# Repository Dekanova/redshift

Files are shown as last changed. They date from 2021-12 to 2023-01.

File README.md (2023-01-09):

# Redshift 

This is the central repository for work on the Redshift PCB.

## Features
- 8kHz polling (USB 2.0 HighSpeed)
- usb-C port
- PAW 3399

## Usage
- KiCad 6.0+ must be installed
- Openinput library from kicad content&lib manager in KiCad

**NOTE:** Encoder 3d file is intentionally not included. If you wish to add it, models are freely downloaded from Alps Alpine [website](https://tech.alpsalpine.com/e/products/cad.html) under EC10E.

## Board Notes
- If connecting USB and debug connectors at the same time, ensure debug supply voltage is under 5v. (some JTAG debuggers have this) 5v supply from debug pins are OK as long as USB is unplugged.
- PcbNew grid size used is 0.1mm

### Credits
A huge thanks to openinput for their generic [KiCad lib](https://github.com/openinput-fw/openinput-kicad-library), as well as their [fully developed PCBs](https://github.com/openinput-fw/sammy) which this PCB is largely based off of.

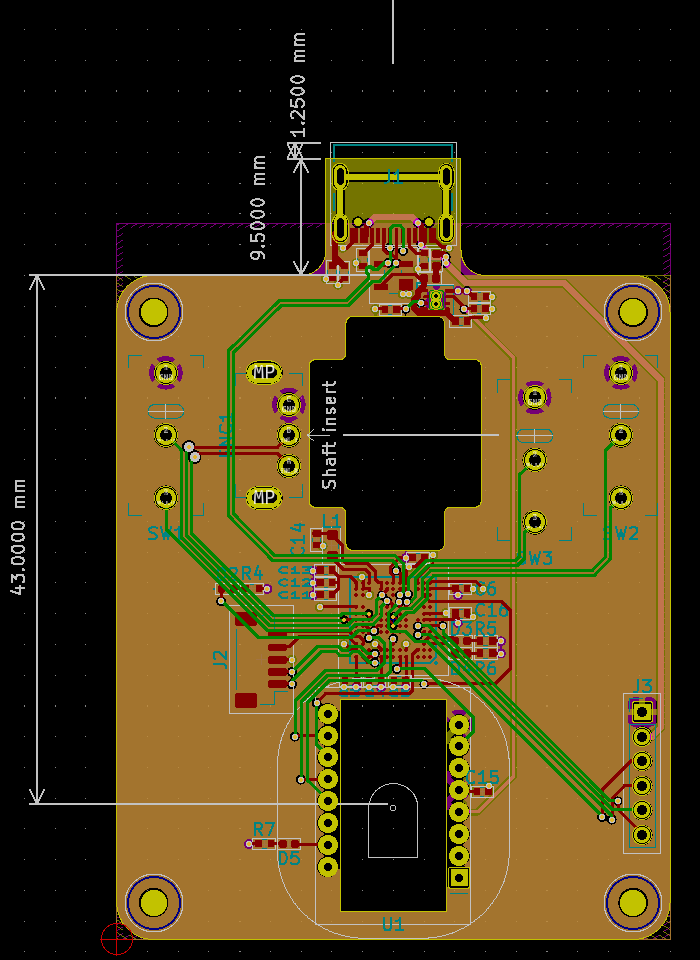
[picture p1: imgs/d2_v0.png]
2d view of PCB Title

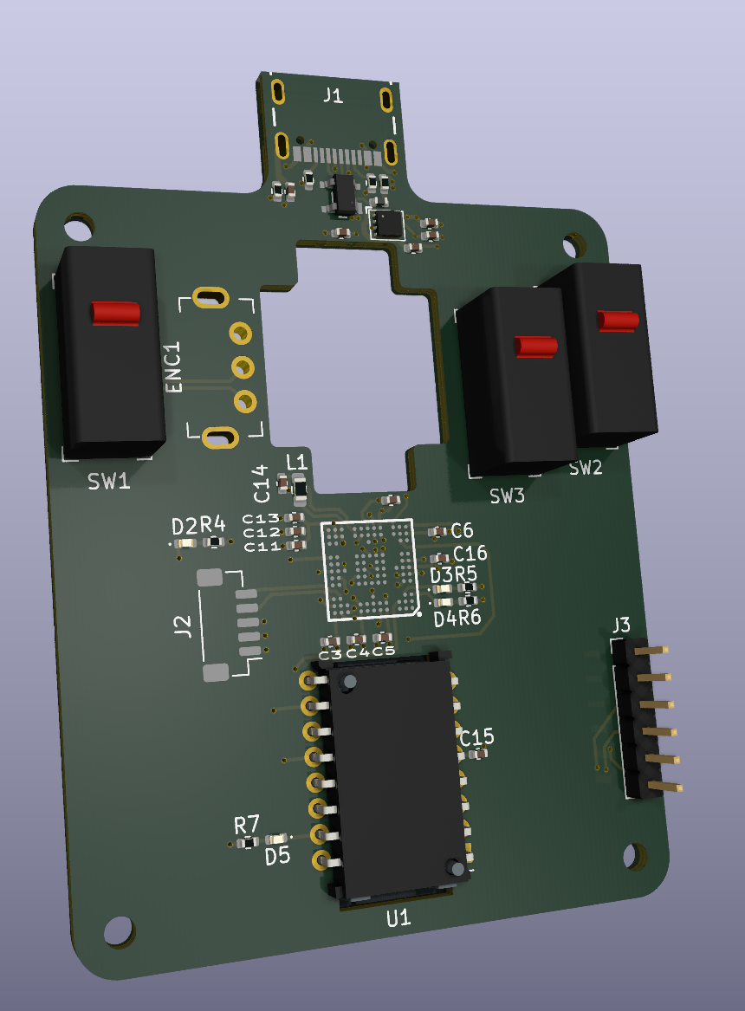
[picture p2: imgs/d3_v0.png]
3d view of PCB Title


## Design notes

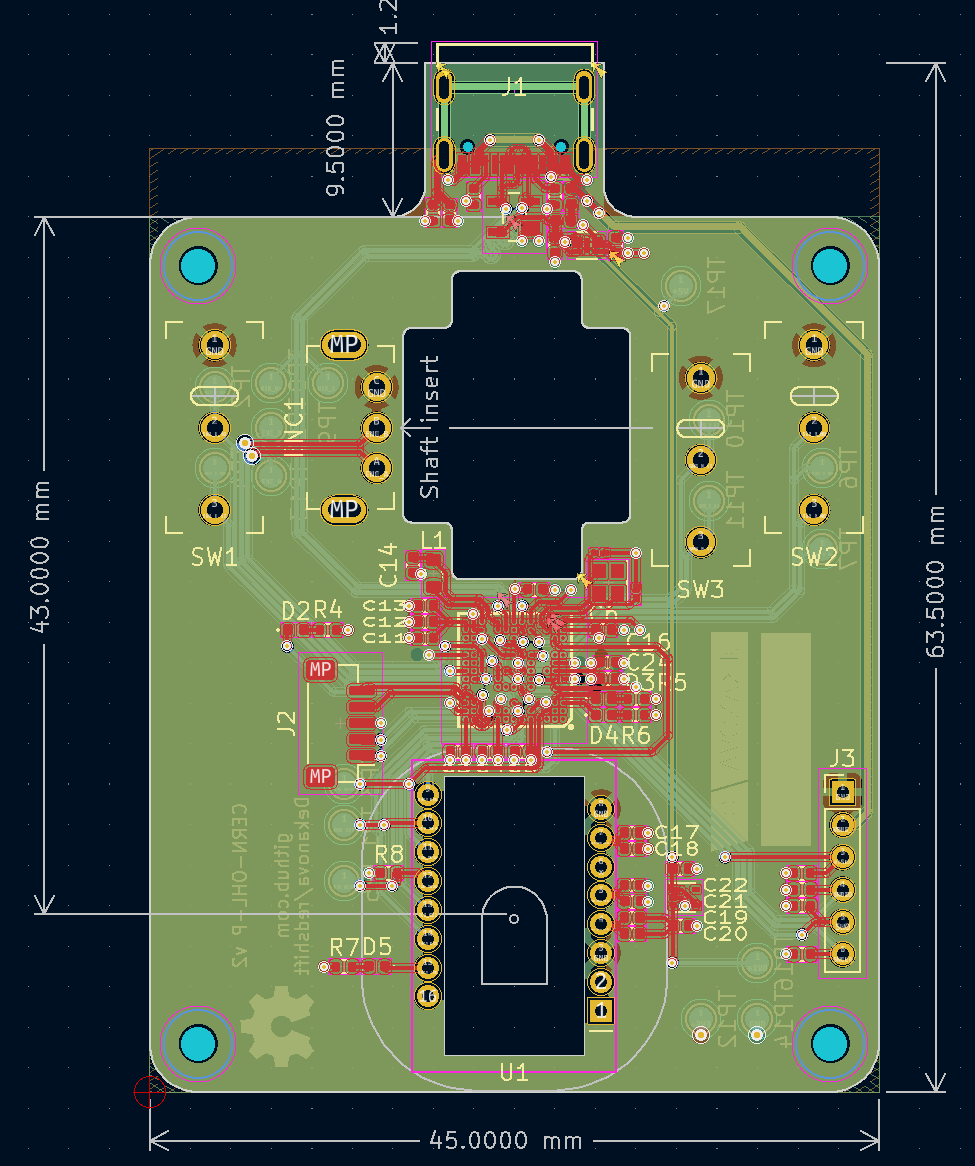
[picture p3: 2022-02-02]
imgs/2d_v0-1.png

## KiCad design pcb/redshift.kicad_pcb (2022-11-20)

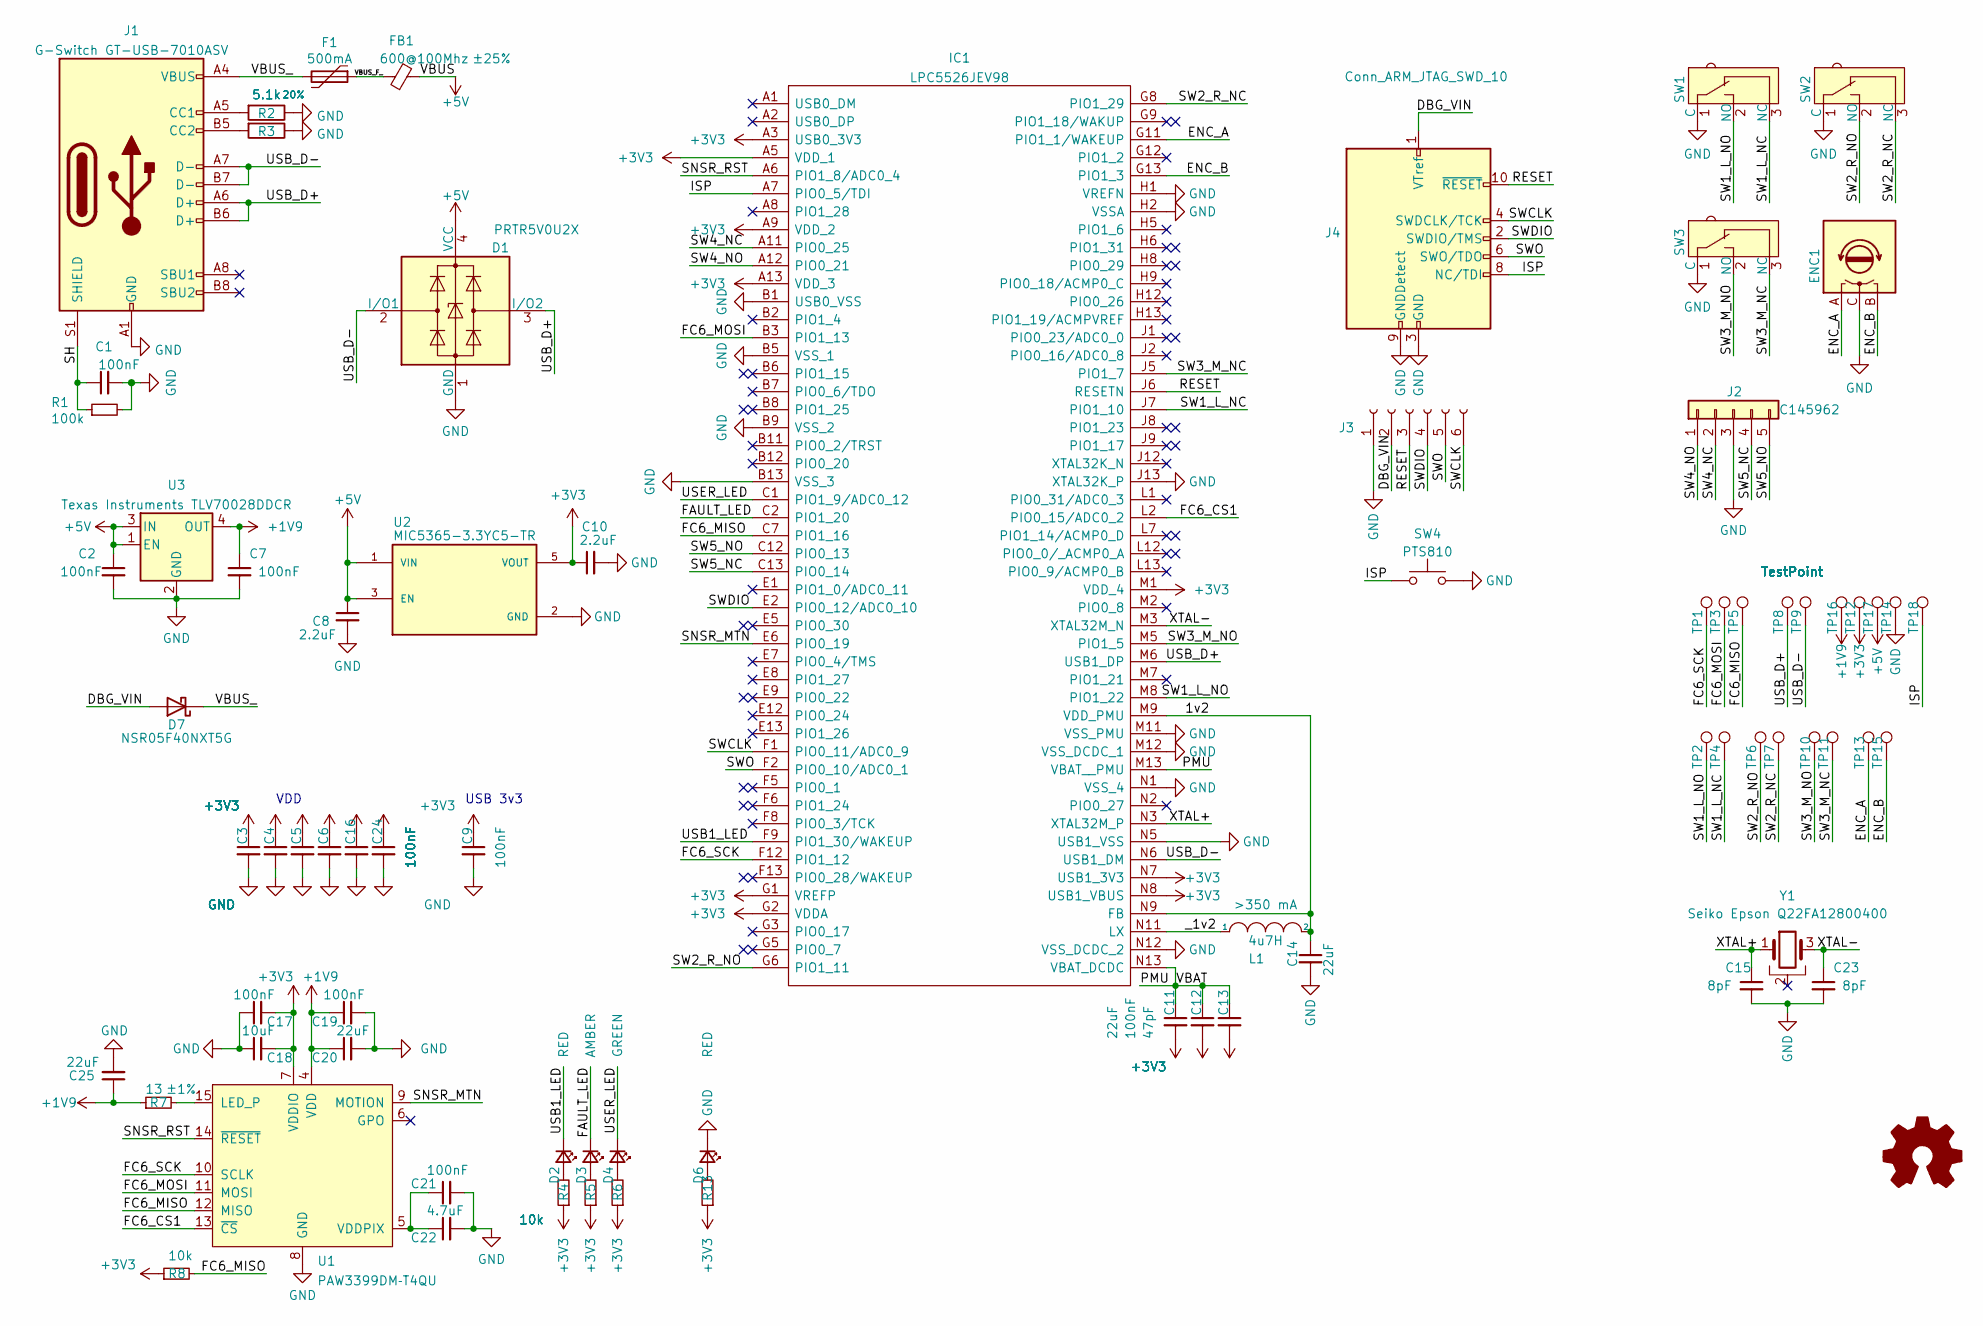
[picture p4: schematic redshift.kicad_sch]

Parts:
C1, C2, C3, C4, C5, C6, C7, C9, C12, C16, C17, C19, C21, C24: 100nF; C_0402_1005Metric; LCSC C1525
C8, C10: 2.2uF; C_0402_1005Metric; LCSC C12530
C11, C14, C20, C25: 22uF; C_0603_1608Metric; LCSC C59461
C13: 47pF; C_0402_1005Metric; LCSC C1567
C15, C23: 8pF; C_0402_1005Metric; LCSC C1578
C18: 10uF; C_0402_1005Metric; LCSC C15525
C22: 4.7uF; C_0402_1005Metric; LCSC C23733
D1: PRTR5V0U2X; BF994S; LCSC C12333
D2, D6: RED; LED_0402_1005Metric; LCSC C965790
D3: AMBER; LED_0402_1005Metric; LCSC C401111
D4: GREEN; LED_0402_1005Metric; LCSC C401111
D7: NSR05F40NXT5G; D_0402_1005Metric; LCSC C146713
ENC1: Rotary_Encoder; RotaryEncoder_Horizontal
F1: 500mA; Fuse_0402_1005Metric; LCSC C17168
FB1: 600@100Mhz; L_0402_1005Metric; Tolerance ±25%; LCSC C142082
IC1: LPC5526JEV98; BGA98C50P13X13_700X700X97N; Manufacturer_Part_Number LPC5528JEV98K; Mouser Part Number 771-LPC5528JEV98K
J1: G-Switch GT-USB-7010ASV; GCT_USB4105-GF-A; LCSC C2988369
J2: C145962; JST_SH_BM05B-SRSS-TB_1x05-1MP_P1.00mm_Vertical
J3: C2935905; PinHeader_1x06_P2.00mm_Vertical
J4: Conn_ARM_JTAG_SWD_10; PinHeader_2x05_P1.27mm_Vertical_SMD; LCSC C2935458
L1: 4u7H; L_0805_2012Metric; LCSC C63166
R1: 100k; R_0402_1005Metric; LCSC C25741
R2, R3: 5.1k; R_0402_1005Metric; Tolerance 20%; LCSC C25905
R4, R5, R6, R8, R13: 10k; R_0402_1005Metric; LCSC C25744
R7: 13; R_0402_1005Metric; Tolerance ±1%; LCSC C368403
SW1, SW2, SW3: SW_SP; SW_Micro_Switch
SW4: PTS810; SW_SPST_B3U-1000P; LCSC C231329
TP1, TP2, TP3, TP4, TP5, TP6, TP7, TP8, TP9, TP10, TP11, TP12, TP13, TP14, TP15, TP16, TP17, TP18: TestPoint; TestPoint_Pad_D1.5mm
U1: PAW3399DM‐T4QU; PXI-DIP-16
U2: MIC5365-3.3YC5-TR; SOT-23-5; PARTREV 3.1 - July 16, 2013; LCSC C82942
U3: Texas Instruments TLV70028DDCR; SOT-23-5; LCSC C507266
Y1: Seiko Epson Q22FA12800400; LCSC C255875

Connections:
+1V9: C7.1, C19.1, C20.1, C25.1, R7.1, TP16.1, U1.4 (VDD), U3.4 (OUT)
+3V3: C3.1, C4.1, C5.1, C6.1, C9.1, C10.1, C11.2, C12.2, C13.2, C16.1, C17.2, C18.2, C24.1, IC1.A3 (USB0_3V3), IC1.A5 (VDD_1), IC1.A9 (VDD_2), IC1.A13 (VDD_3), IC1.G1 (VREFP), IC1.G2 (VDDA), IC1.M1 (VDD_4), IC1.N7 (USB1_3V3), IC1.N8 (USB1_VBUS), R4.1, R5.1, R6.1, R8.1, R13.1, TP12.1, U1.7 (VDDIO), U2.5 (VOUT)
+5V: C2.1, C8.1, D1.4 (VCC), FB1.2, TP17.1, U2.1 (VIN), U2.3 (EN), U3.1 (EN), U3.3 (IN)
/1v2: C14.1, IC1.M9 (VDD_PMU), IC1.N9 (FB), L1.2
/DBG_VIN: D7.2 (A), J3.2, J4.1 (VTref)
/ENC_A: ENC1.A, IC1.G11 (PIO1_1/WAKEUP), TP13.1
/ENC_B: ENC1.B, IC1.G13 (PIO1_3), TP15.1
/FAULT_LED: D3.1 (K), IC1.C2 (PIO1_20)
/FC6_CS1: IC1.L2 (PIO0_15/ADC0_2), U1.13 (~CS)
/FC6_MISO: IC1.C7 (PIO1_16), R8.2, TP5.1, U1.12 (MISO)
/FC6_MOSI: IC1.B3 (PIO1_13), TP3.1, U1.11 (MOSI)
/FC6_SCK: IC1.F12 (PIO1_12), TP1.1, U1.10 (SCLK)
/ISP: IC1.A7 (PIO0_5/TDI), J4.8 (NC/TDI), SW4.1, TP18.1
/PMU: C11.1, C12.1, C13.1, IC1.M13 (VBAT__PMU), IC1.N13 (VBAT_DCDC)
/RESET: IC1.J6 (RESETN), J3.3, J4.10 (~RESET)
/SH: C1.1, J1.S1 (SHIELD), J1.S2 (SHIELD), J1.S3 (SHIELD), J1.S4 (SHIELD), R1.1
/SNSR_MTN: IC1.E6 (PIO0_19), U1.9 (MOTION)
/SNSR_RST: IC1.A6 (PIO1_8/ADC0_4), U1.14 (~RESET)
/SW1_L_NC: IC1.J7 (PIO1_10), SW1.3 (NC), TP4.1
/SW1_L_NO: IC1.M8 (PIO1_22), SW1.2 (NO), TP2.1
/SW2_R_NC: IC1.G8 (PIO1_29), SW2.3 (NC), TP7.1
/SW2_R_NO: IC1.G6 (PIO1_11), SW2.2 (NO), TP6.1
/SW3_M_NC: IC1.J5 (PIO1_7), SW3.3 (NC), TP11.1
/SW3_M_NO: IC1.M5 (PIO1_5), SW3.2 (NO), TP10.1
/SW4_NC: IC1.A11 (PIO0_25), J2.2
/SW4_NO: IC1.A12 (PIO0_21), J2.1
/SW5_NC: IC1.C13 (PIO0_14), J2.4
/SW5_NO: IC1.C12 (PIO0_13), J2.5
/SWCLK: IC1.F1 (PIO0_11/ADC0_9), J3.6, J4.4 (SWDCLK/TCK)
/SWDIO: IC1.E2 (PIO0_12/ADC0_10), J3.4, J4.2 (SWDIO/TMS)
/SWO: IC1.F2 (PIO0_10/ADC0_1), J3.5, J4.6 (SWO/TDO)
/USB1_LED: D2.1 (K), IC1.F9 (PIO1_30/WAKEUP)
/USB_D+: D1.3 (I/O2), IC1.M6 (USB1_DP), J1.A6 (D+), J1.B6 (D+), TP8.1
/USB_D-: D1.2 (I/O1), IC1.N6 (USB1_DM), J1.A7 (D-), J1.B7 (D-), TP9.1
/USER_LED: D4.1 (K), IC1.C1 (PIO1_9/ADC0_12)
/VBUS_: D7.1 (K), F1.2, J1.A4 (VBUS), J1.A9 (VBUS), J1.B4 (VBUS), J1.B9 (VBUS)
/VBUS_F_: F1.1, FB1.1
/XTAL+: C15.1, IC1.N3 (XTAL32M_P), Y1.1
/XTAL-: C23.1, IC1.M3 (XTAL32M_N), Y1.3
/_1v2: IC1.N11 (LX), L1.1
GND: C1.2, C2.2, C3.2, C4.2, C5.2, C6.2, C7.2, C8.2, C9.2, C10.2, C14.2, C15.2, C16.2, C17.1, C18.1, C19.2, C20.2, C21.2, C22.2, C23.2, C24.2, C25.2, D1.1 (GND), D6.1 (K), ENC1.C, IC1.B1 (USB0_VSS), IC1.B5 (VSS_1), IC1.B9 (VSS_2), IC1.B13 (VSS_3), IC1.H1 (VREFN), IC1.H2 (VSSA), IC1.J13 (XTAL32K_P), IC1.M11 (VSS_PMU), IC1.M12 (VSS_DCDC_1), IC1.N1 (VSS_4), IC1.N5 (USB1_VSS), IC1.N12 (VSS_DCDC_2), J1.A1 (GND), J1.A12 (GND), J1.B1 (GND), J1.B12 (GND), J2.3, J3.1, J4.3 (GND), J4.5 (GND), J4.9 (GNDDetect), R1.2, R2.1, R3.1, SW1.1 (C), SW2.1 (C), SW3.1 (C), SW4.2, TP14.1, U1.3 (GND), U1.8 (GND), U2.2 (GND), U3.2 (GND)
unnamed: C21.1, C22.1, U1.5 (VDDPIX)
unnamed: D2.2 (A), R4.2
unnamed: D3.2 (A), R5.2
unnamed: D4.2 (A), R6.2
unnamed: D6.2 (A), R13.2
unnamed: J1.A5 (CC1), R2.2
unnamed: J1.B5 (CC2), R3.2
unnamed: R7.2, U1.15 (LED_P)

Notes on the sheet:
USB 3v3
VDD

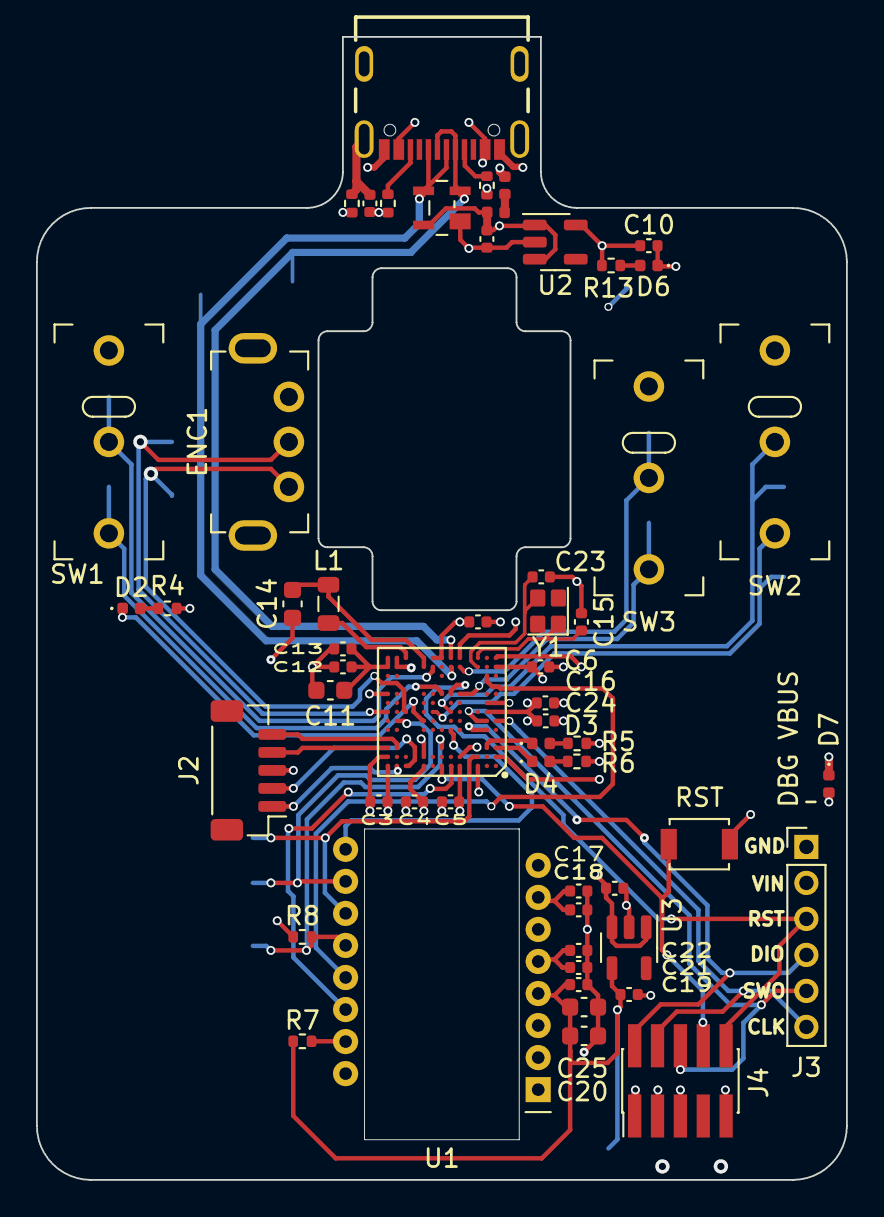
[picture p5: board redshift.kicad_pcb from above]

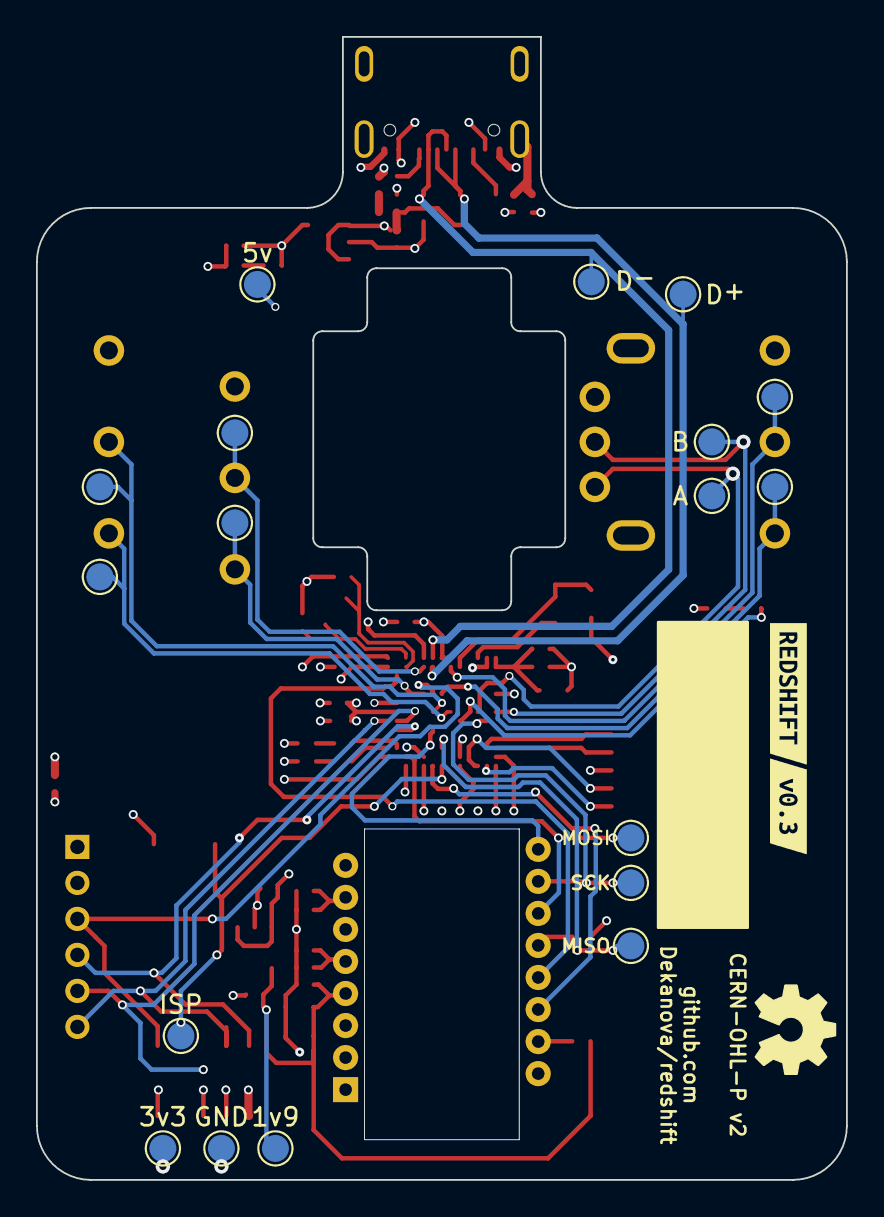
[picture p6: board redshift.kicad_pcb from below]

Board: 4 copper layers, 45.0 x 63.5 mm, 77 parts (20 on the bottom side), 49 nets.

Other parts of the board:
kibuzzard-637894B3: G***; kibuzzard-637894B3
kibuzzard-63789540: G***; kibuzzard-63789540

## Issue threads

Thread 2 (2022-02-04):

1.9v LDO outputs ~3.0v

mriise, 2022-02-04:
On 2 boards now, it may be the wrong ordered product, but most likely design err and something is shorted.

mriise, 2022-03-06:
schematic was incorrect

Closed 2022-03-06.

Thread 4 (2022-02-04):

Replace LEDs with normal sized ones

mriise, 2022-02-04:
0402 LEDs are kinda whack to buy, should use more generic sized ones (maybe even RGB)

great-houk, 2022-09-27:
I'm currently planning on adjusting the design to use 0603 [(like these)](https://www.digikey.com/en/products/detail/liteon/LTST-C191KGKT/386835) for all the LEDs except for the fault. That one can be a 0606 RGB LED [(like this)](https://www.digikey.com/en/products/detail/everlight-electronics-co-ltd/EAST1616RGBB4/8510361)
Both seem like common enough sizes that finding suitable LEDs from any vendor shouldn't be a problem

mriise, 2022-10-01:
sounds good, though for the RGB like that it would need 3 dedicated GPIO pins to control it which isn't great. Honestly something like ws2812 with a single pin for control is nicer but will be a bit more of a pain to program for.

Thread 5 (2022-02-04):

Update encoder footprint

mriise, 2022-02-04:
https://github.com/openinput-fw/openinput-kicad-library/pull/7 fixes encoder footprint.

Closed 2022-03-06.

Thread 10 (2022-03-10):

Condiser PTN5150H

mriise, 2022-03-10:
USB-C alternate mode detection, could be useful to turn the USB port into a debug accessory for debugging work thru just a USB-C cable and an adapter chip.

There are a host of considerations to make before this will be a real option.
such as
- USB IF certification requires that entering into debug accessory mode is extremely intentional and known by the user.
- this will only detect change in modes, not route the pins. there may be another chip that would do this
- using the 2 extra pins can get SCLK and SWDIO for flashing, what other 2 pins can be re-used for RESET and SWO? (probably steal one of the D+/- pairs)

mriise, 2023-08-03:
1: can be addressed by requiring that all firmware changes are authenticated (which requires secure boot)
2: this is easy enough to check on boot for the main mcu, switch the pins, then self-reset.
3: added requirement that this should be reverseable.

making a debug probe and no. 1 is probably the biggest burden here. PTN5150H is able to detect debug acessory, so we are all good on that front.

atm i think putting an rp2040 as the probe using modified picoprobe firmware. Though all of this should be fairly down the line in scope. using a normal debug probe setup will work fine for a good while.
https://github.com/raspberrypi/picoprobe

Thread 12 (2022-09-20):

Add debounce circuit to scroll wheel

great-houk, 2022-09-20:
The manufacturer of the scroll wheel recommends adding a simple RC debouncing circuit, and there currently isn't one.

mriise, 2022-09-21:
This is intentional ATM, RC denouncing inherently adds latency as it smooths out the voltage differences. This may be something we will need to have, but I had chosen to implement fancy denouncing in firmware instead since we would be able to design what tradeoffs we want to have for it.

Feel free to add them and we can just not place them if we decide to do it all in firmware.

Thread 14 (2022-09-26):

PAW3399 Pin 15 (LED_P) Shouldn't be connected to an LED

great-houk, 2022-09-26:
Pin 15 of the PAW3399 is the anode for the built-in infrared LED, and in the datasheet they connect it to ground through a resistor. In the schematic, it's connect to ground through a resistor and external red LED, which doesn't seem intentional and might cause problems.

great-houk, 2022-09-26:
Update: I just realized that the current schematic has the built-in LED's and the external LED's anodes connected, so there is no possible way for it to work

Closed 2022-10-10.

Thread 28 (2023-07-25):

Fix pin numbers on sensor LDO

great-houk, 2023-07-25:
Currently, the 1.9v output is on pin 4 of the LDO, when in reality that pin is NC and the actual output is pin 5.

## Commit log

2021-11-30 fix git files
    [redshift.kicad_pcb, redshift.kicad_sch]
2021-12-02 add USB and some power wires
    [redshift.kicad_pcb, redshift.kicad_sch]
2021-12-05 route USB and power lines, fix ESD chip
    [redshift.kicad_pcb, redshift.kicad_sch]
2021-12-11 add trace header and LEDs
    [redshift.kicad_pcb, redshift.kicad_sch]
2021-12-23 pre v0.1
    [redshift.kicad_pcb, redshift.kicad_sch]
2022-01-17 add lpc55 footprint from solokeys, release v0.1
    [redshift-B_Cu.gbr, redshift-B_Mask.gbr, redshift-B_Paste.gbr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]
2022-01-17 Add GCT usb-C 2.0 port footprint to local project
    [redshift.kicad_pcb]
2022-02-16 add ISP pin
    [redshift.kicad_pcb, redshift.kicad_sch]
2022-03-06 fix #2, add missing lib source
    [redshift.kicad_pcb, redshift.kicad_sch]
2022-03-06 update encoder footprint fixes #5
    [redshift.kicad_pcb]
2022-03-06 update USB footprint, remove pad inside SWDIO trace
    [redshift.kicad_pcb, redshift.kicad_sch]
2022-03-10 Debug fixes
    - add 10 pin debug connector
    - remove uneeded pull up resistors on pins (MCU has internal ones)
    - add a diode to protect reverse current on the debug pins
    [redshift.kicad_pcb, redshift.kicad_sch]
2022-03-12 widen USB pair to within spec
    [redshift.kicad_pcb]
2022-03-21 bump version, use proper spec Caps
    [redshift.kicad_pcb, redshift.kicad_sch]
2022-09-18 ground unused USB line per datasheet, use smaller switch for ISP
    [redshift.kicad_pcb, redshift.kicad_sch]
2022-09-18 Replaced Old LDO
    [redshift.kicad_pcb, redshift.kicad_sch]
2022-09-19 Added cheap and slightly larger 3.3v LDO
    [redshift.kicad_pcb, redshift.kicad_sch]
2022-09-26 Added the only missing lib I could find: the mcu
    [redshift.kicad_pcb, redshift.kicad_sch]
2022-10-02 Fixed VDD/IO, LED_P, and removed Sensor LED from Schematic
    [redshift.kicad_sch]
2022-10-02 Modified PCB to reflect changes Moved some silkscreens and parts around to fit better Changed default VIA size to match what's being used
    [redshift.kicad_pcb, redshift.kicad_sch]
2022-10-08 Change +1V8 To +1V9 Also align everything to a 50 mil grid
    [redshift.kicad_sch]
2022-10-24 Add missing 3D Models Replace missing 3D models with similar ones Add some models to gitignore
    [redshift.kicad_pcb, redshift.kicad_sch]
2022-11-10 Change design constraints to better match JLC Fix all DRC errors
    [redshift.kicad_pcb]
2022-11-11 Small Changes to USB Footprint Make USB test points hopefully less detrimental
    [redshift.kicad_sch]
2022-11-12 Update USB data lines to be ~90 ohms
    [redshift.kicad_pcb]
2022-11-13 Give all components LCSC listings Change some components to match stock
    [BOM-redshift.csv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]
2022-11-13 Add ground fill to top and bottom
    [redshift.kicad_pcb]
2022-11-13 Add random VIAs to help ground planes connect
    [BOM-redshift.csv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]
2022-11-13 Forgot to save, look at previous
    [redshift.kicad_pcb]
2022-11-13 Change 3.3v LDO LCSC part, original had 3 pins
2022-11-14 Test generating JLC files again
    [BOM-redshift.csv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]
2022-11-14 remove top and bottom fill, small naming fixes
    [redshift.kicad_pcb]
2022-11-15 Fixes #25
    [redshift.kicad_pcb, redshift.kicad_sch]
2022-11-16 Place JTAG/SWO Connector Put 0Ω Resistor in Fuse Place Find LCSC Part for 13Ω Resistor
2022-11-16 Remove C145962 from Parts List
    [redshift.kicad_pcb]
2022-11-17 Fix small silkscreen error Remove uneccesary AR-Check file
    [redshift.kicad_pcb]
2022-11-19 small fixes and updating board from schmatic
    [redshift.kicad_pcb, redshift.kicad_sch]
2022-11-19 remove jlcpcb output from git
    [BOM-redshift.csv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]
2022-11-20 Add part numbers back based off of 64fe10091f3e64ca899d2226f0a24cf256eb9be7
    [redshift.kicad_pcb, redshift.kicad_sch]

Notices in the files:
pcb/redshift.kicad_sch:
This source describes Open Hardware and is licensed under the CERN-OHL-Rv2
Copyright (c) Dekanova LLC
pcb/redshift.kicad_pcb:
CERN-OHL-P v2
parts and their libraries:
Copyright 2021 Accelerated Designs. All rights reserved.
